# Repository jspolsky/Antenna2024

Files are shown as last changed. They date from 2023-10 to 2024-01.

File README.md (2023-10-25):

Future Turtles 2024 Public LED Display
====

For the Future Turtles 44' LED mast this year, I'm hoping to improve the array of short, 6' tall "whips" that accompany it.

* I want to have 24 whips instead of 12 whips
* They will be about 3' apart instead of 6', so the patterns will be more interesting
* I plan to improve the cabling substantially, allowing the whips to be daisy-chained instead of each having a cable connecting it all the way back to the controller.

To make the daisy chaining work, each whip will have it's own mini control box sitting at its feet.

* The mini control box will have a Teensy 4.0 to receive commands from the main controller and display things on the LEDs.
* Power will be daisy-chained too. To minimize voltage drop, the power will be transmitted at 24 volts. Each control box will have a tiny 24 volt -> 12 volt DC transformer to power the LEDs and an even smaller 12 volt -> 5 volt buck converter to power its Teensy.
* The data will be sent from the controller over a single RS-485 bus which can be daisy-chained from one mini control box to the next.

Right now I am working on the code in **Whips** which runs on a Teensy 4.1 in the main control box, and on all the Teensy 4.0s in the mini control boxes.

In the main control box it runs in "DOM" mode (#define DOM) and sends commands to the mini control boxes. The mini control boxes run in "SUB" mode (#define SUB) where they receive these commands and are responsible for the LED display of a single whip.

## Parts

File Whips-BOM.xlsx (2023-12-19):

Item | Use | Model / Details | Qty Needed | Qty on Hand | Qty on Order | URL | Details
Whips |  | 5150 Whips WH-1876P (6') | 24 | 26 | 0 | https://5150whips.com/collections/whips/products/2-led-whips-4ft?variant=30326186278990 | 12 are in Reno
XLR (Male) |  | Neutrik XX | 24 | 31 | 0 | https://www.bhphotovideo.com/c/product/871095-REG/Neutrik_Male_and_Female_XLR.html
XLR (Female) |  | Neutrik XX | 27 | 29 | 0 | https://www.bhphotovideo.com/c/product/871095-REG/Neutrik_Male_and_Female_XLR.html
3 Core 18 awg Wire | XLR F to Case |  | 1 ft | 100 ft | 0 | https://www.amazon.com/gp/product/B07ZGFVH81/ref=ppx_yo_dt_b_search_asin_title?ie=UTF8&psc=1
Polycase Enclosure |  | SK-13 Grey with Clear Top | 27 | 28 | 0 | https://www.polycase.com/sk-13
M16 Cable Gland |  | uxcell 10Pcs M16 Waterproof IP68 Nylon Cable Gland Joint Adjustable Locknut for 4mm-8mm Dia Cable Wire | 135 | 160 | 0 | https://www.amazon.com/dp/B01MZ0L51V?psc=1&ref=ppx_yo2ov_dt_b_product_details
PCB |  | Custom | 27 | 0 | 30 |  | JLCPCB Order Placed
Speaker |  | CQRobot 403W-Dupont2.54 | 0 | 27 | 0 | https://www.amazon.com/dp/B0822XCPT8?ref=ppx_yo2ov_dt_b_product_details&th=1 | Cancelled
Stepdown 24-12 Converter |  | EKYLIN DC 24V to 12V 3A | 27 | 27 | 0 | https://www.amazon.com/gp/product/B01EFUHHLK/ref=ppx_yo_dt_b_asin_title_o08_s00?ie=UTF8&th=1 | Different versions ordered
Nylon screw and nut set | Speaker to PCB | M2.5 x 8mm | 0 | 108 | 0 | https://www.amazon.com/dp/B0C2C9GCDW?psc=1&ref=ppx_yo2ov_dt_b_product_details | Cancelled
12v-5v Stepdown 1 amp |  | Traco TSR1-2450E | 27 | 34 | 0 | https://octopart.com/search?q=Traco+TSR1-2450E&currency=USD&specs=0
WAGO nuts | 24 volt power | 221 3-way | 54 | 100 | 0 | https://www.amazon.com/dp/B077WZV3D4?psc=1&smid=A2P5I4NW0QQAX1&ref_=chk_typ_imgToDp
Power Cable | 24 volt power | 12 awg speaker wire | 94.5 ft | 100 ft | 0 | https://www.amazon.com/gp/product/B071GDNKDZ/ref=ppx_yo_dt_b_search_asin_title?ie=UTF8&th=1
Data Cable | RS422 signal | CAT 5 or similar | 94.5 ft | 94.5 ft | 0
XT60 connectors | RS422 signal | AMASS XT60H M+F pair | 27 | 30 | 0 | https://www.amazon.com/dp/B07PZ15Z2D?psc=1&smid=A30FXSQQLNNWKA&ref_=chk_typ_imgToDp
XT90S connectors | 24 volt power | AMASS XT90S M+F pair | 27 | 30 | 0 | https://www.amazon.com/dp/B07YTG9DVR?psc=1&smid=A1JGQIWP459RKC&ref_=chk_typ_imgToDp
3d Printed Supports | inside case | (custom) | 54 | 2 |  |  | print
Teensy 4.1 |  | PJRC Teensy 4.1 TEENSY41_NE | 27 | 27 | 0 | https://www.pjrc.com/store/teensy41.html | ordered from Adafruit
Micro SD Card |  | 8GB Micro SD Flash | 27 | 29 | 0 | https://www.amazon.com/dp/B0876H387X?psc=1&smid=A2SFGDK0SQGMP8&ref_=chk_typ_imgToDp

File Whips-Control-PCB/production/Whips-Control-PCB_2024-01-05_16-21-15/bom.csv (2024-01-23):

Designator | Footprint | Quantity | Value | LCSC Part #
J1 | PhoenixContact_MSTBA_2,5_2-G-5,08_1x02_P5.08mm_Horizontal | 1 | PWR
J2 | PhoenixContact_MSTBA_2,5_2-G-5,08_1x02_P5.08mm_Horizontal | 1 | DATA
RV1 | Potentiometer_Alpha_RD901F-40-00D_Single_Vertical | 1 | R_Potentiometer_US
U1 | Teensy41_Minimal | 1 | Teensy4.1_Minimal
U2 | Max485-Module | 1 | MAX485E
U3 | Vishay_MOLD-3Pin | 1 | TSOP341xx

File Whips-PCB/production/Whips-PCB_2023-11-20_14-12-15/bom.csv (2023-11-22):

Designator | Footprint | Quantity | Value | LCSC Part #
C1, C4 | 0402 | 2 | 0.1uF | C1525
C2, C5 | 0402 | 2 | 10uF | C15525
C6, C7 | 0402 | 2 | 220pF | C1530
D1 | 0603 | 1 | LED | C2286
D2 | 0603 | 1 | LED | C2290
D3, D4 | Everlight 99-218GLM2C-L7277SGU-TR8-T0-ES side view LED | 2 | LED | C605463
H1 | Turtle-Art-2024 | 1 | DNP (LOGO)
J1 | TerminalBlock_RND_205-00001_1x02_P5.00mm_Horizontal | 1 | 12 VDC | C8404
J2, J5 | TerminalBlock_RND_205-00001_1x02_P5.00mm_Horizontal | 2 | RS422 BUS | C8404
J3 | TerminalBlock_RND_205-00001_1x02_P5.00mm_Horizontal | 1 | SPEAKER 4OHM | C8404
J4 | TerminalBlock_RND_205-00002_1x03_P5.00mm_Horizontal | 1 | TO WHIP | C8401
R1, R2 | 0603 | 2 | 20K | C4184
R10, R11, R6, R9 | 0402 | 4 | 470 | C25117
R3, R4 | 0603 | 2 | 10K | C25804
R5 | 0402 | 1 | 120 | C25079
R7 | 0402 | 1 | 1M | C26083
R8 | 0402 | 1 | 100K | C25741
SW2 | SW_DIP_SPSTx06_Slide_6.7x16.8mm_W7.62mm_P2.54mm_LowProfile | 1 | SW_DIP_x06 | C2859410
U2 | SOIC-8_3.9x4.9mm_P1.27mm | 1 | MAX485ESA+T | C19738
U3 | SOIC-14_3.9x8.7mm_P1.27mm | 1 | SN74AHCT125DR | C155176
U4 | Converter_DCDC_TRACO_TSR-1_THT | 1 | TSR_1-2450 | DNP
U5 | MAX98357AETE+T | 1 | MAX98357AETE+T | C910544
U6 | Teensy41_Minimal | 1 | Teensy4.1_Minimal | DNP

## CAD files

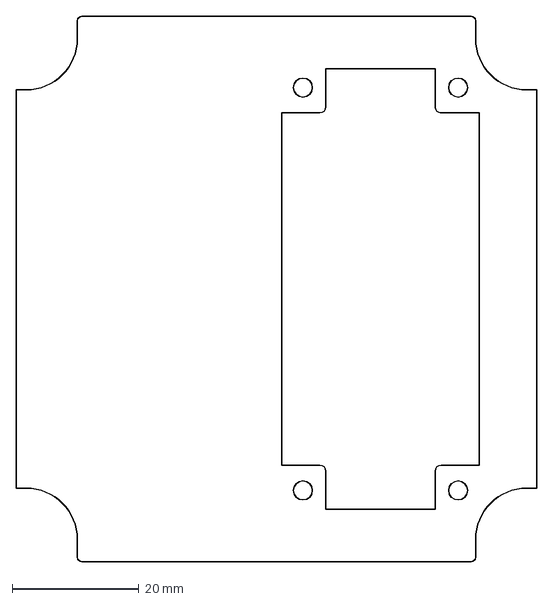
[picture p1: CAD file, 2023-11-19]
Whips-PCB/whippcb2.dxf
82.0 x 86.0 mm

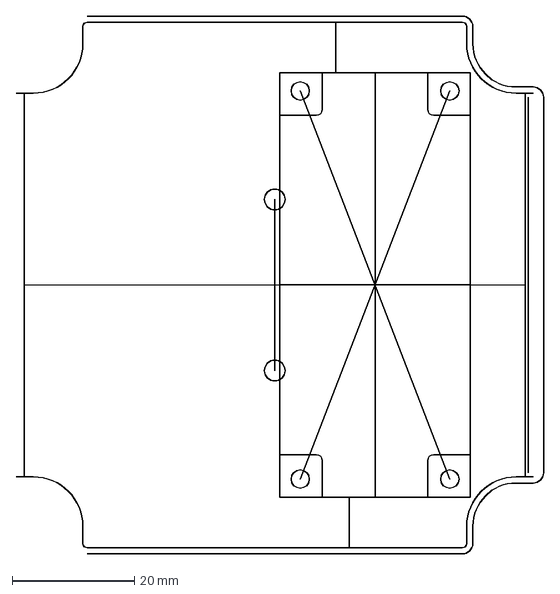
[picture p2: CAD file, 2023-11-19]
Whips-PCB/whippcb.dxf
86.3 x 88.0 mm

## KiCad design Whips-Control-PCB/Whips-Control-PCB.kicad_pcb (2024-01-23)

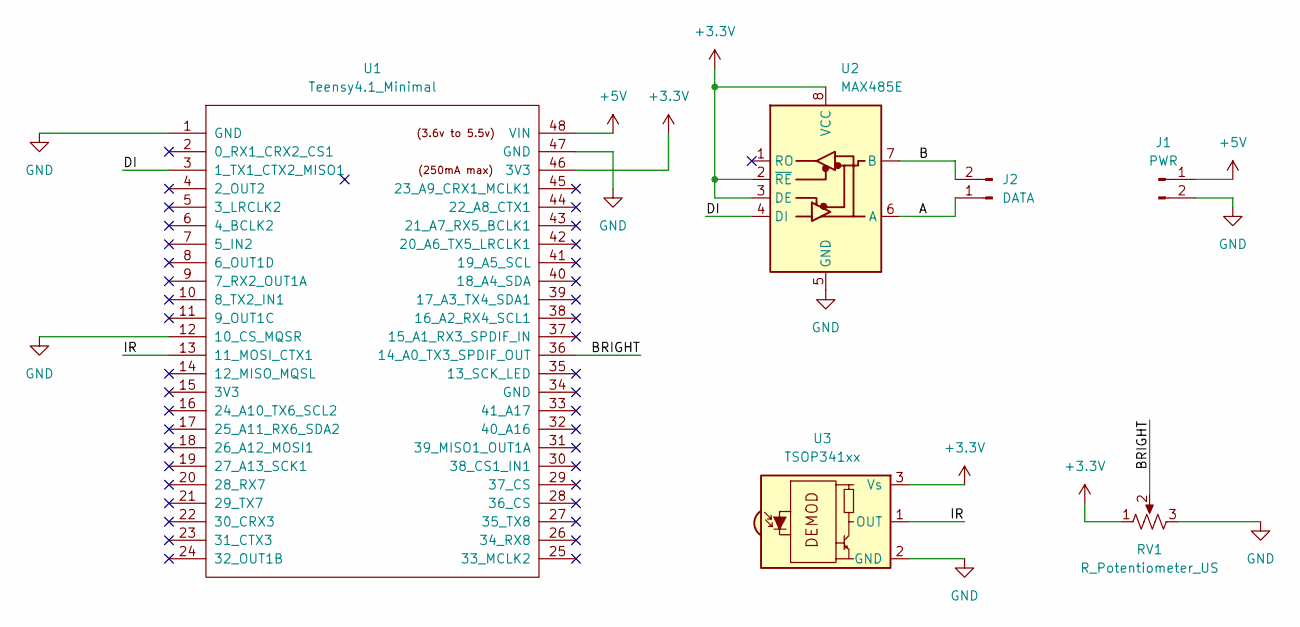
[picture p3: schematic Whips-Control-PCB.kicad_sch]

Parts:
J1: PWR; PhoenixContact_MSTBA_2,5_2-G-5,08_1x02_P5.08mm_Horizontal
J2: DATA; PhoenixContact_MSTBA_2,5_2-G-5,08_1x02_P5.08mm_Horizontal
RV1: R_Potentiometer_US; Potentiometer_Alpha_RD901F-40-00D_Single_Vertical
U1: Teensy4.1_Minimal; Teensy41_Minimal
U2: MAX485E; Max485-Module
U3: TSOP341xx; Vishay_MOLD-3Pin

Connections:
+3.3V: RV1.1, U1.46 (3V3), U2.2 (~RE), U2.3 (DE), U2.8 (VCC), U3.3 (Vs)
+5V: J1.1, U1.48 (VIN)
/A: J2.1, U2.6 (A)
/B: J2.2, U2.7 (B)
/BRIGHT: RV1.2, U1.36 (14_A0_TX3_SPDIF_OUT)
/DI: U1.3 (1_TX1_CTX2_MISO1), U2.4 (DI)
/IR: U1.13 (11_MOSI_CTX1), U3.1 (OUT)
GND: J1.2, RV1.3, U1.1 (GND), U1.12 (10_CS_MQSR), U1.47 (GND), U2.5 (GND), U3.2 (GND)

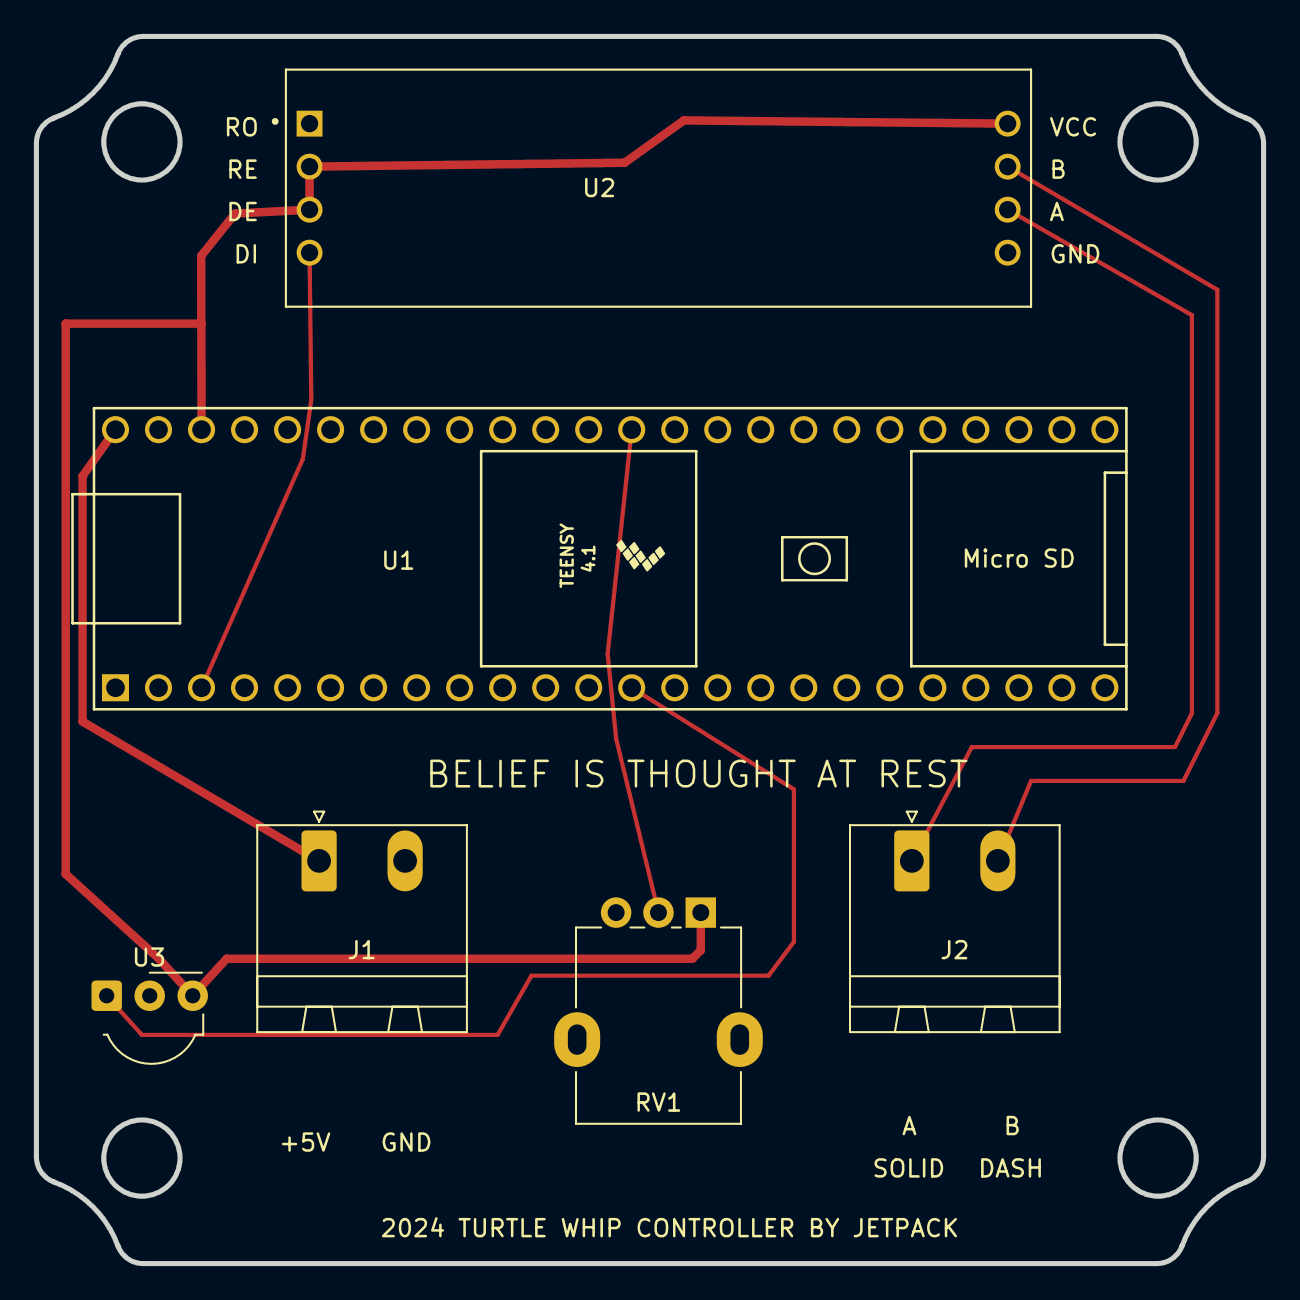
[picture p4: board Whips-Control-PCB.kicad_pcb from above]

Board: 2 copper layers, 72.5 x 72.5 mm, 6 parts (0 on the bottom side), 8 nets.

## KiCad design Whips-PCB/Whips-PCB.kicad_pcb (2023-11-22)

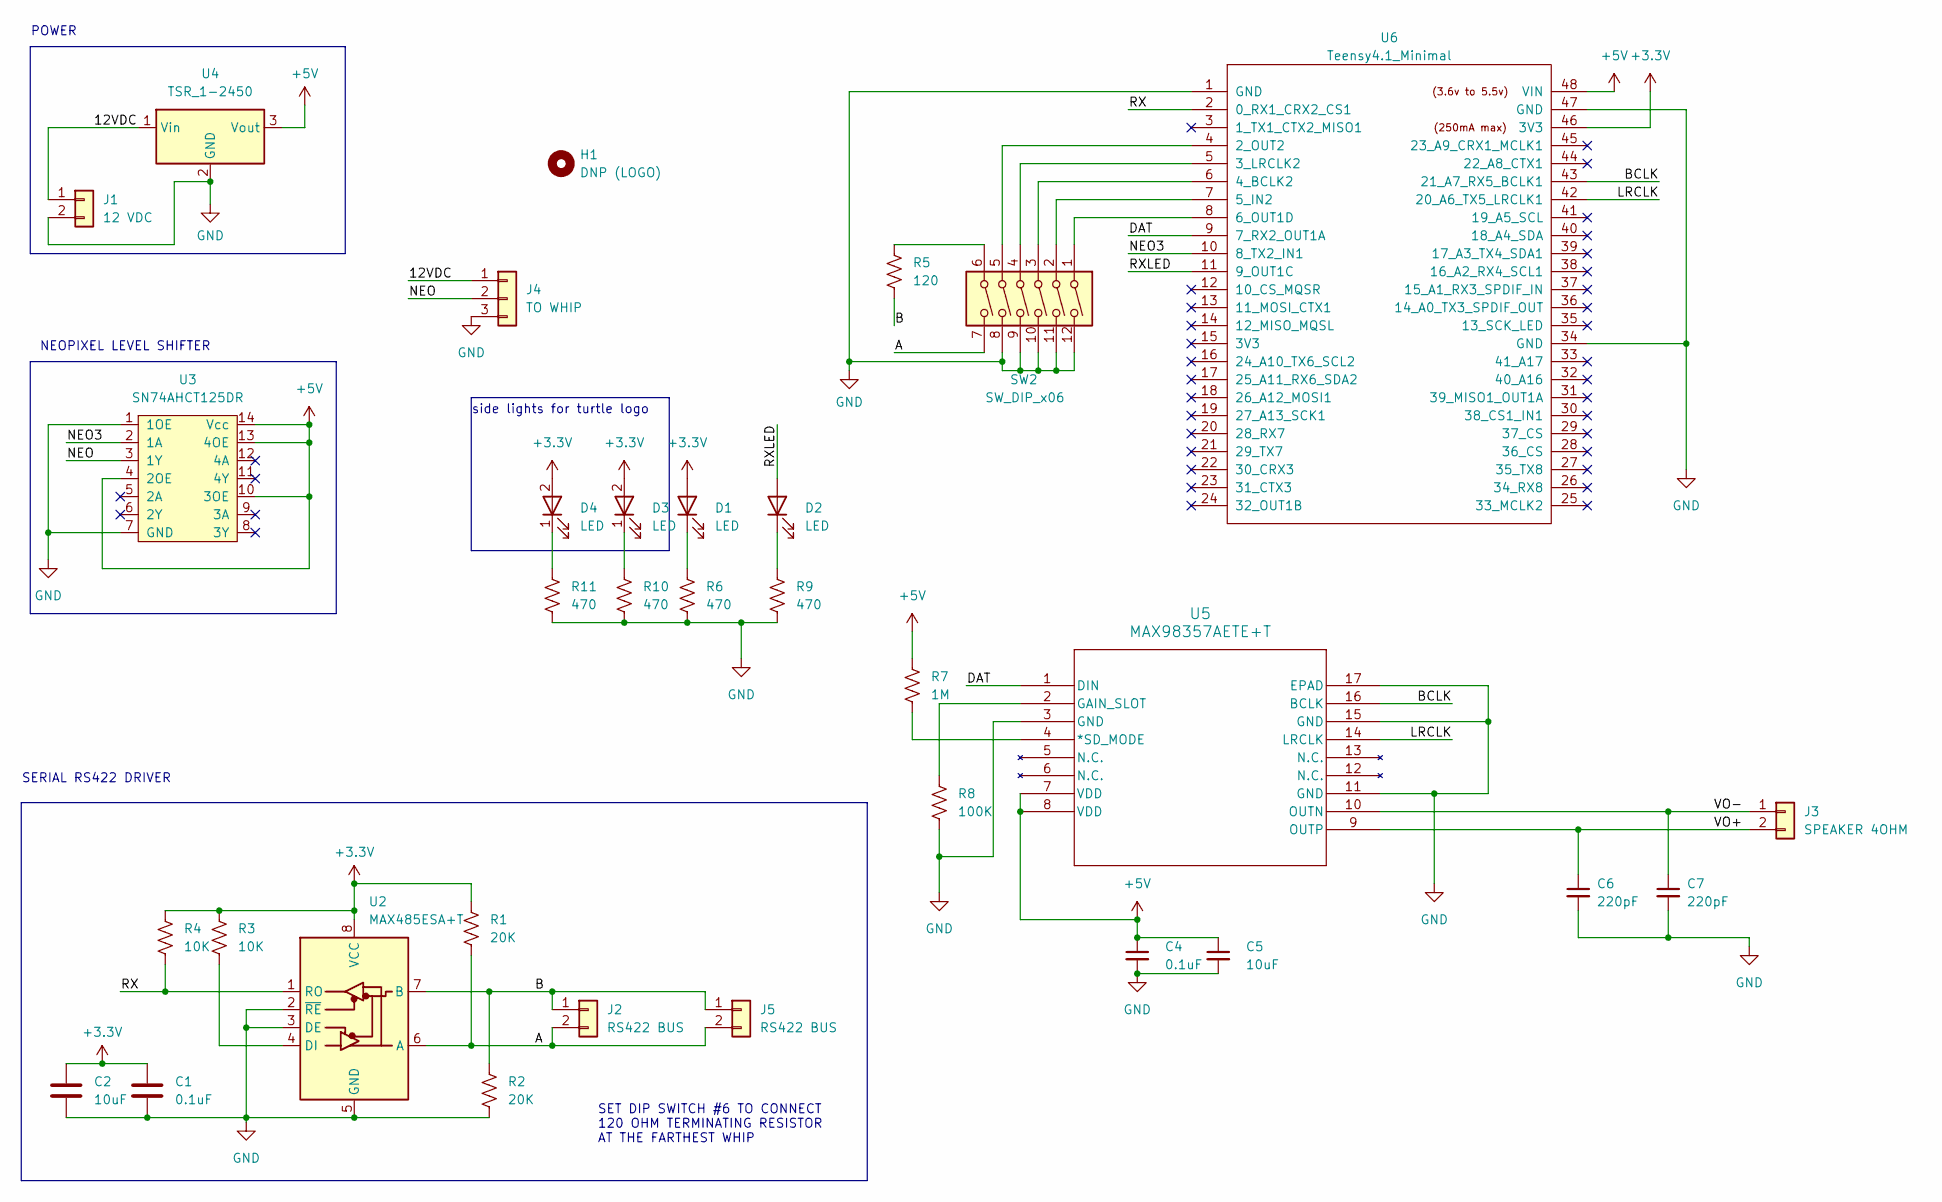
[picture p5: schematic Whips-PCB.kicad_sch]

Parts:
C1, C4: 0.1uF; C_0402_1005Metric; LCSC C1525
C2, C5: 10uF; C_0402_1005Metric; LCSC C15525
C6, C7: 220pF; C_0402_1005Metric; LCSC C1530
D1: LED; LED_0603_1608Metric; LCSC C2286
D2: LED; LED_0603_1608Metric; LCSC C2290
D3, D4: LED; Everlight 99-218GLM2C-L7277SGU-TR8-T0-ES side view LED; LCSC C605463
H1: DNP (LOGO); Turtle-Art-2024
J1: 12 VDC; TerminalBlock_Phoenix_MKDS-1,5-2_1x02_P5.00mm_Horizontal; LCSC C8404
J2, J5: RS422 BUS; TerminalBlock_Phoenix_MKDS-1,5-2_1x02_P5.00mm_Horizontal; LCSC C8404
J3: SPEAKER 4OHM; TerminalBlock_Phoenix_MKDS-1,5-2_1x02_P5.00mm_Horizontal; LCSC C8404
J4: TO WHIP; TerminalBlock_Phoenix_MKDS-1,5-3_1x03_P5.00mm_Horizontal; LCSC C8401
R1, R2: 20K; R_0603_1608Metric; LCSC C4184
R3, R4: 10K; R_0603_1608Metric; LCSC C25804
R5: 120; R_0402_1005Metric; LCSC C25079
R6, R9, R10, R11: 470; R_0402_1005Metric; LCSC C25117
R7: 1M; R_0402_1005Metric; LCSC C26083
R8: 100K; R_0402_1005Metric; LCSC C25741
SW2: SW_DIP_x06; SW_DIP_SPSTx06_Slide_6.7x16.8mm_W7.62mm_P2.54mm_LowProfile; LCSC C2859410
U2: MAX485ESA+T; SOIC-8_3.9x4.9mm_P1.27mm; LCSC C19738
U3: SN74AHCT125DR; SOIC-14_3.9x8.7mm_P1.27mm; LCSC C155176
U4: TSR_1-2450; Converter_DCDC_TRACO_TSR-1_THT; LCSC DNP
U5: MAX98357AETE+T; LCSC C910544
U6: Teensy4.1_Minimal; Teensy41_Minimal; LCSC DNP

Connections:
+3.3V: C1.1, C2.1, D1.2 (A), D3.2 (A), D4.2 (A), R1.1, R3.1, R4.1, U2.8 (VCC), U6.46 (3V3)
+5V: C4.1, C5.1, R7.1, U3.4 (2OE), U3.10 (3OE), U3.13 (4OE), U3.14 (Vcc), U4.3 (Vout), U5.7 (VDD), U5.8 (VDD), U6.48 (VIN)
/12VDC: J1.1, J4.1, U4.1 (Vin)
/A: J2.2, J5.2, R1.2, SW2.7, U2.6 (A)
/B: J2.1, J5.1, R2.2, R5.2, U2.7 (B)
/BCLK: U5.16 (BCLK), U6.43 (21_A7_RX5_BCLK1)
/DAT: U5.1 (DIN), U6.9 (7_RX2_OUT1A)
/LRCLK: U5.14 (LRCLK), U6.42 (20_A6_TX5_LRCLK1)
/NEO: J4.2, U3.3 (1Y)
/NEO3: U3.2 (1A), U6.10 (8_TX2_IN1)
/RX: R4.2, U2.1 (RO), U6.2 (0_RX1_CRX2_CS1)
/RXLED: D2.2 (A), U6.11 (9_OUT1C)
/VO+: C6.1, J3.2, U5.9 (OUTP)
/VO-: C7.1, J3.1, U5.10 (OUTN)
GND: C1.2, C2.2, C4.2, C5.2, C6.2, C7.2, J1.2, J4.3, R2.1, R6.2, R8.2, R9.2, R10.2, R11.2, SW2.8, SW2.9, SW2.10, SW2.11, SW2.12, U2.2 (~RE), U2.3 (DE), U2.5 (GND), U3.1 (1OE), U3.7 (GND), U4.2 (GND), U5.3 (GND), U5.11 (GND), U5.15 (GND), U5.17 (EPAD), U6.1 (GND), U6.34 (GND), U6.47 (GND)
unnamed: D1.1 (K), R6.1
unnamed: D2.1 (K), R9.1
unnamed: D3.1 (K), R10.1
unnamed: D4.1 (K), R11.1
unnamed: R5.1, SW2.6
unnamed: R3.2, U2.4 (DI)
unnamed: R7.2, U5.4 (*SD_MODE)
unnamed: R8.1, U5.2 (GAIN_SLOT)
unnamed: SW2.5, U6.4 (2_OUT2)
unnamed: SW2.4, U6.5 (3_LRCLK2)
unnamed: SW2.3, U6.6 (4_BCLK2)
unnamed: SW2.2, U6.7 (5_IN2)
unnamed: SW2.1, U6.8 (6_OUT1D)

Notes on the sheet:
POWER
SERIAL RS422 DRIVER
side lights for turtle logo
NEOPIXEL LEVEL SHIFTER
SET DIP SWITCH #6 TO CONNECT 120 OHM TERMINATING RESISTOR AT THE FARTHEST WHIP

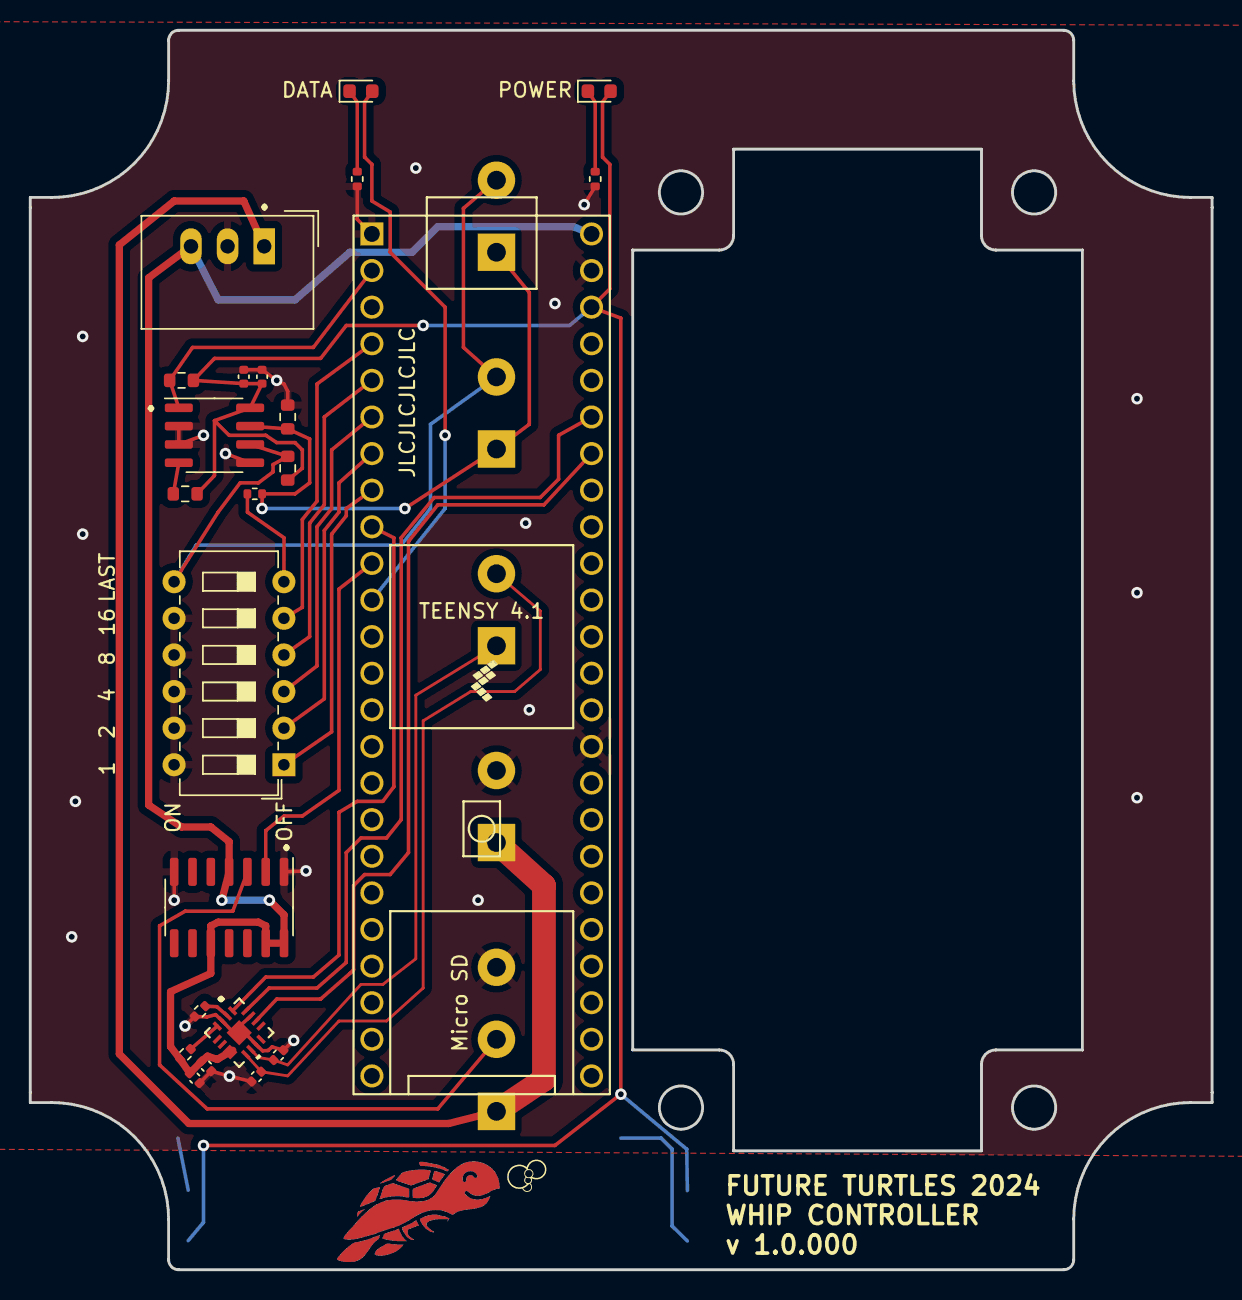
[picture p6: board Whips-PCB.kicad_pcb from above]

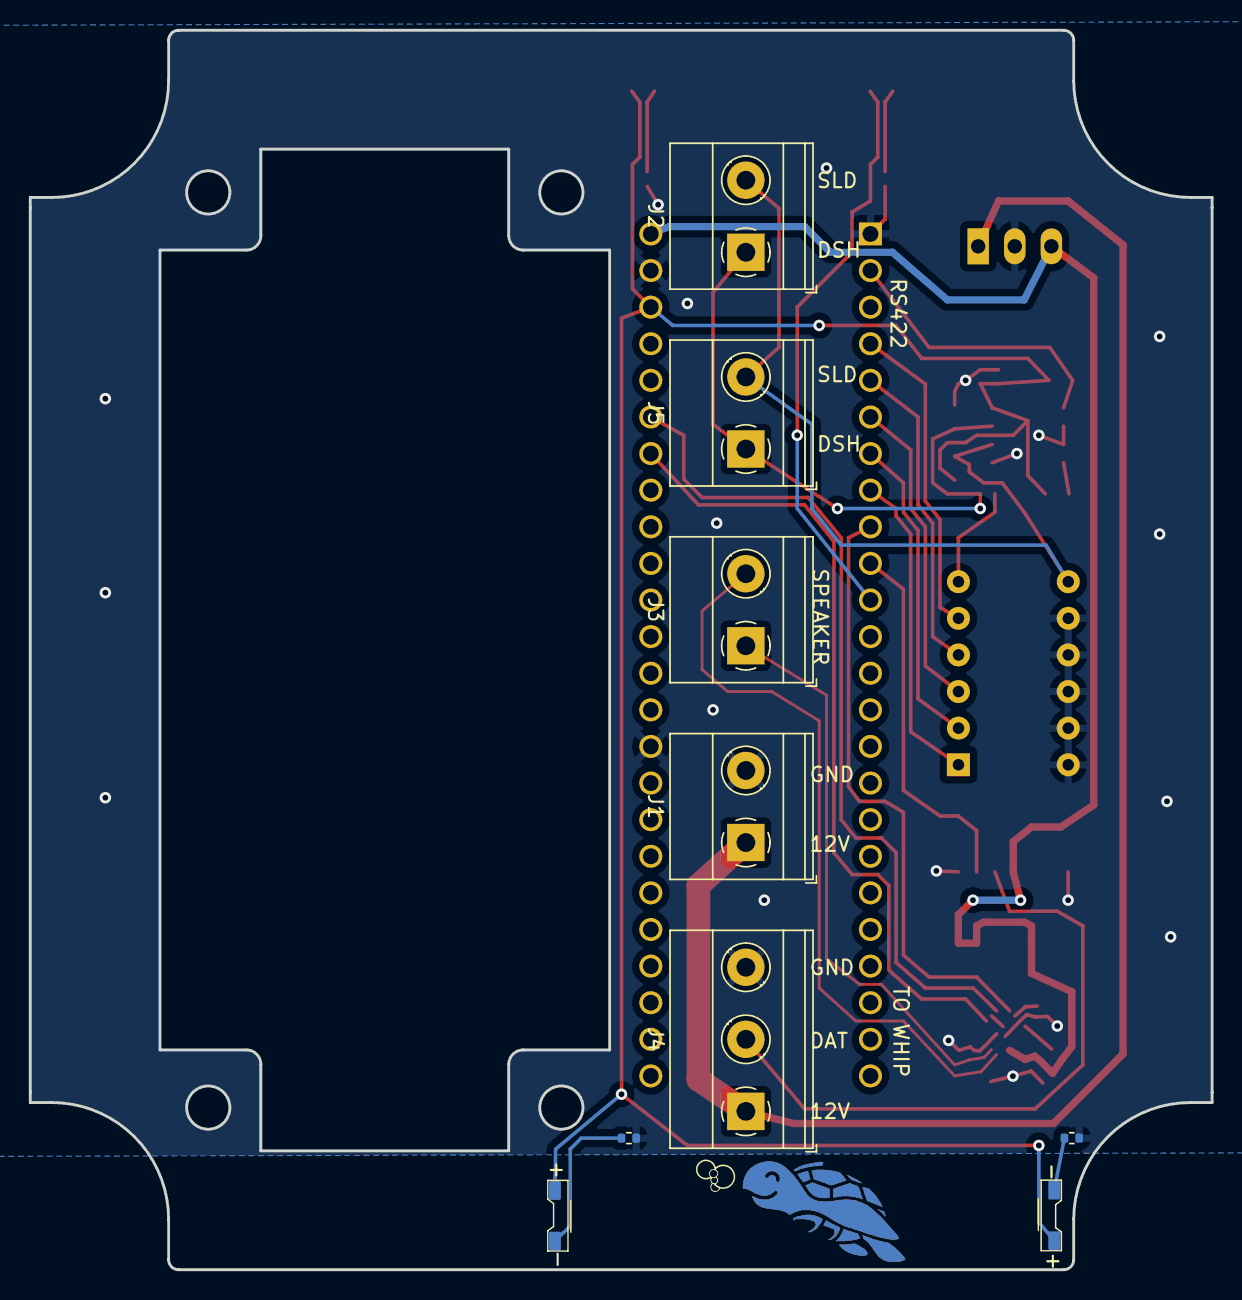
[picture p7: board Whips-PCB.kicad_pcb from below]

Board: 2 copper layers, 82.0 x 86.0 mm, 33 parts (9 on the bottom side), 28 nets.

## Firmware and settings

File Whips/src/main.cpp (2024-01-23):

#include <Arduino.h>

#include "pins.h"
#include "Util.h"
#include "Led.h"
#include "LedShow.h"
#include "DipSwitch.h"
#include "SdCard.h"
#include "Gif.h"
#include "IR.h"

static bool domMode;

void setup()
{

  pinMode(pinGndMeansDom, INPUT_PULLUP);

  Util::setup();
  delay(100);

  if (!(SD.begin(pinSDCardCS)))
  {
    dbgprintf("Unable to access sd card\n");
    return;
  }

  domMode = (digitalReadFast(pinGndMeansDom) == LOW);
  dbgprintf("Whip controller in %s mode\n", domMode ? "DOM" : "SUB");

  if (domMode)
  {
    LedShow::setup();
    IR::setup();
  }
  else
  {
    DipSwitch::setup();
    Led::setup();
  }
  Gif::setup();
}

void loop()
{
  if (domMode)
  {
    IR::Op op = IR::loop();
    LedShow::loop(op);

    EVERY_N_SECONDS(20)
    {
      LedShow::loop(IR::nextImageSuggested);
    }
  }
  else
  {
    DipSwitch::loop();
    Led::loop();
  }
}

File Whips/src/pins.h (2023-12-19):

#define pinLEDStrip 8

// Which SD Card are we using?
// BUILTIN_SDCARD - for Teensy 4.1
// 10 - when connected to external SD Card using SPI
//      Currently not using this because it is not fast enough
//      and causes audio to sound crap
#define pinSDCardCS BUILTIN_SDCARD
// #define pinSDCardCS 10

#define pinStatus LED_BUILTIN
#define pinBrightness A0
#define pinLEDRxIndicator 9
#define pinGndMeansDom 10
#define pinIR 11

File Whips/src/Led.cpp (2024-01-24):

#include <Arduino.h>
#include <PacketSerial.h>
#include <CRC16.h>
#include <CRC.h>

#include "pins.h"
#include "Util.h"
#include "Led.h"
#include "Commands.h"
#include "DipSwitch.h"
#include "Gif.h"

namespace Led
{

    CRGB leds[NUM_LEDS];
    PacketSerial packetSerial;
    uint8_t brightness = 32;

    void setup()
    {
        Serial1.begin(2000000);
        packetSerial.setStream(&Serial1);
        packetSerial.setPacketHandler(&onPacketReceived);

        FastLED.addLeds<WS2812SERIAL, pinLEDStrip, BGR>(leds, NUM_LEDS);
        FastLED.setBrightness(brightness);
        FastLED.showColor(CRGB::DarkOrange);

        pinMode(pinLEDRxIndicator, OUTPUT);
    }

    void loop()
    {
        packetSerial.update();

        EVERY_N_MILLIS(200)
        {
            digitalWriteFast(pinLEDRxIndicator, LOW);
        }
    }

    void onPacketReceived(const uint8_t *buffer, size_t size)
    {
        if (size < sizeof(cmdUnknown))
        {
            // impossible packet doesn't even have room for checksum and command
            return;
        }

        cmdUnknown *punk = (cmdUnknown *)buffer;

        uint16_t checksum = punk->checksum;
        punk->checksum = 0; // when packet checksum was calculated, these 2 bytes were 0

        if (checksum != calcCRC16(buffer, size))
        {
            // packet garbled
            dbgprintf("garbled packet. Size was %d\n", size);
            return;
        }

        digitalWriteFast(pinLEDRxIndicator, HIGH);

        if (punk->whip != DipSwitch::getWhipNumber() && punk->whip != 255)
        {
            // not a message for us
            return;
        }

        switch (punk->chCommand)
        {
        case 'c':
        {
            cmdSetWhipColor *pSetWhipColor = (cmdSetWhipColor *)buffer;
            FastLED.showColor(pSetWhipColor->rgb);
        }
        break;

        case 'b':
        {

            cmdSetBrightness *pSetBrightness = (cmdSetBrightness *)buffer;
            if (brightness != pSetBrightness->brightness)
            {
                brightness = pSetBrightness->brightness;
                FastLED.setBrightness(128);
                int ixBrightness = map(brightness, 0, 255, 0, NUM_LEDS);
                for (int i = 0; i < ixBrightness; i++)
                {
                    leds[i] = CRGB::White;
                }
                for (int i = ixBrightness; i < NUM_LEDS; i++)
                {
                    leds[i] = CRGB::Black;
                }
                FastLED.show();
                FastLED.delay(200);
                FastLED.setBrightness(pSetBrightness->brightness);
            }
        }
        break;

        case 'g':
        {
            if (DipSwitch::getWhipNumber() <= 23)
            {
                static uint16_t iGifLoaded = 0;

                cmdShowGIFFrame *pShowGIFFrame = (cmdShowGIFFrame *)buffer;

                if (iGifLoaded != pShowGIFFrame->iGifNumber)
                {
                    Gif::LoadGif(iGifLoaded = pShowGIFFrame->iGifNumber);
                    dbgprintf("Loading gif number %d\n", pShowGIFFrame->iGifNumber);
                }
                Gif::GetFrame(pShowGIFFrame->frame, leds);
                FastLED.show();
            }
            else
            {
                FastLED.showColor(CRGB::Red);
            }
            break;
        }

        case 'i':
        {
            uint8_t whip = DipSwitch::getWhipNumber();

            for (int i = 0; i < NUM_LEDS; i++)
                leds[i] = CRGB::Black;

            for (int i = 0; i < 5; i++)
            {
                for (int led = i * 20; led < (i + 1) * 20 - 3; led++)
                {
                    if (whip & 0x01)
                        leds[led] = CRGB::White;
                }
                for (int led = (i + 1) * 20 - 3; led < (i + 1) * 20; led++)
                {
                    leds[led] = CRGB::Red;
                }
                whip >>= 1;
            }

            FastLED.show();
            break;
        }
        }
    }
}

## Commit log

2023-10-27 ok got it working - problem was level shifter in hardware
    [Led.cpp]
2023-11-02 Dip Switches to determine whip address
2023-11-03 Schematics for whips controller - everything but audio
    [Whips-PCB.kicad_pcb, Whips-PCB.kicad_sch]
2023-11-03 improved rs422
    [Whips-PCB.kicad_sch]
2023-11-06 StatusLed conflicts with SPI
2023-11-06 updated schematic to reflect audio and sd card
    [Whips-PCB.kicad_sch]
2023-11-07 volume adjustment. Use maximum gain in hardware
    [Whips-PCB.kicad_sch]
2023-11-08 pack structures on the wire to save bytes!
2023-11-09 pots for brightness (not implemented), volume
    [Whips-PCB.kicad_sch]
2023-11-09 teensy 4.0->4.1
    [Whips-PCB.kicad_sch]
2023-11-09 starting to find part numbers and footprints
    [Whips-PCB.kicad_sch]
2023-11-17 support for indicator LEDS
    [Whips-PCB.kicad_sch]
2023-11-17 provided parts and footprints for LEDs
    [Whips-PCB.kicad_sch]
2023-11-19 full PCB - everything except decorations
    [Whips-PCB.kicad_pcb, Whips-PCB.kicad_sch, whippcb.dxf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]
2023-11-19 cute turtle logo
    [Whips-PCB.kicad_pcb, Whips-PCB.kicad_sch, bom.csv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]
2023-11-20 Much better turtle logo with backlights
    [Whips-PCB.kicad_pcb, Whips-PCB.kicad_sch]
2023-11-22 Latest PCBs and some new gitignore stuff
    [Whips-PCB.kicad_pcb, Whips-PCB.kicad_sch, bom.csv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]
2023-11-26 Stub GIF reading code is working
    [Whips-BOM.xlsx, rectangles.xlsx]
2023-11-27 framework for animated gif from dom to sub
2023-11-28 figgered out last bug in rendering animated gifs!
    [Led.cpp, main.cpp]
2023-11-28 stuff arrived
    [Whips-BOM.xlsx]
2023-11-29 some sample/test gif animations
2023-12-19 Speakers didn't work. No sound
    [Whips-BOM.xlsx]
2023-12-19 Every gif frame packet includes gif #
2024-01-23 PCB for controller
    [Whips-Control-PCB.kicad_pcb, Whips-Control-PCB.kicad_sch, bom.csv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]
